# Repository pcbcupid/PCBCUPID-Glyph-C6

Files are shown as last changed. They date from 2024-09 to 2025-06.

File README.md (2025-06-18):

# PCBCUPID-GLYPH-C6-PCB

PCBCUPID-GLYPH-C6

This repo contains open source PCB files for PCBCUPID Glyph C6
This particular PCB is designed using Kicad v8.0

**This design has been built and tested successfully!**
For more details, check out the product pages at

   * [Glyph-C6](https://shop.pcbcupid.com/product/gd002/)

We are here to build India's largest open source hardware community, If you like to support
please consider buying the product from the above link!

[Creative Commons Attribution, Share-Alike license](https://creativecommons.org/licenses/by-sa/4.0/deed.en)
All text above must be included in any redistribution

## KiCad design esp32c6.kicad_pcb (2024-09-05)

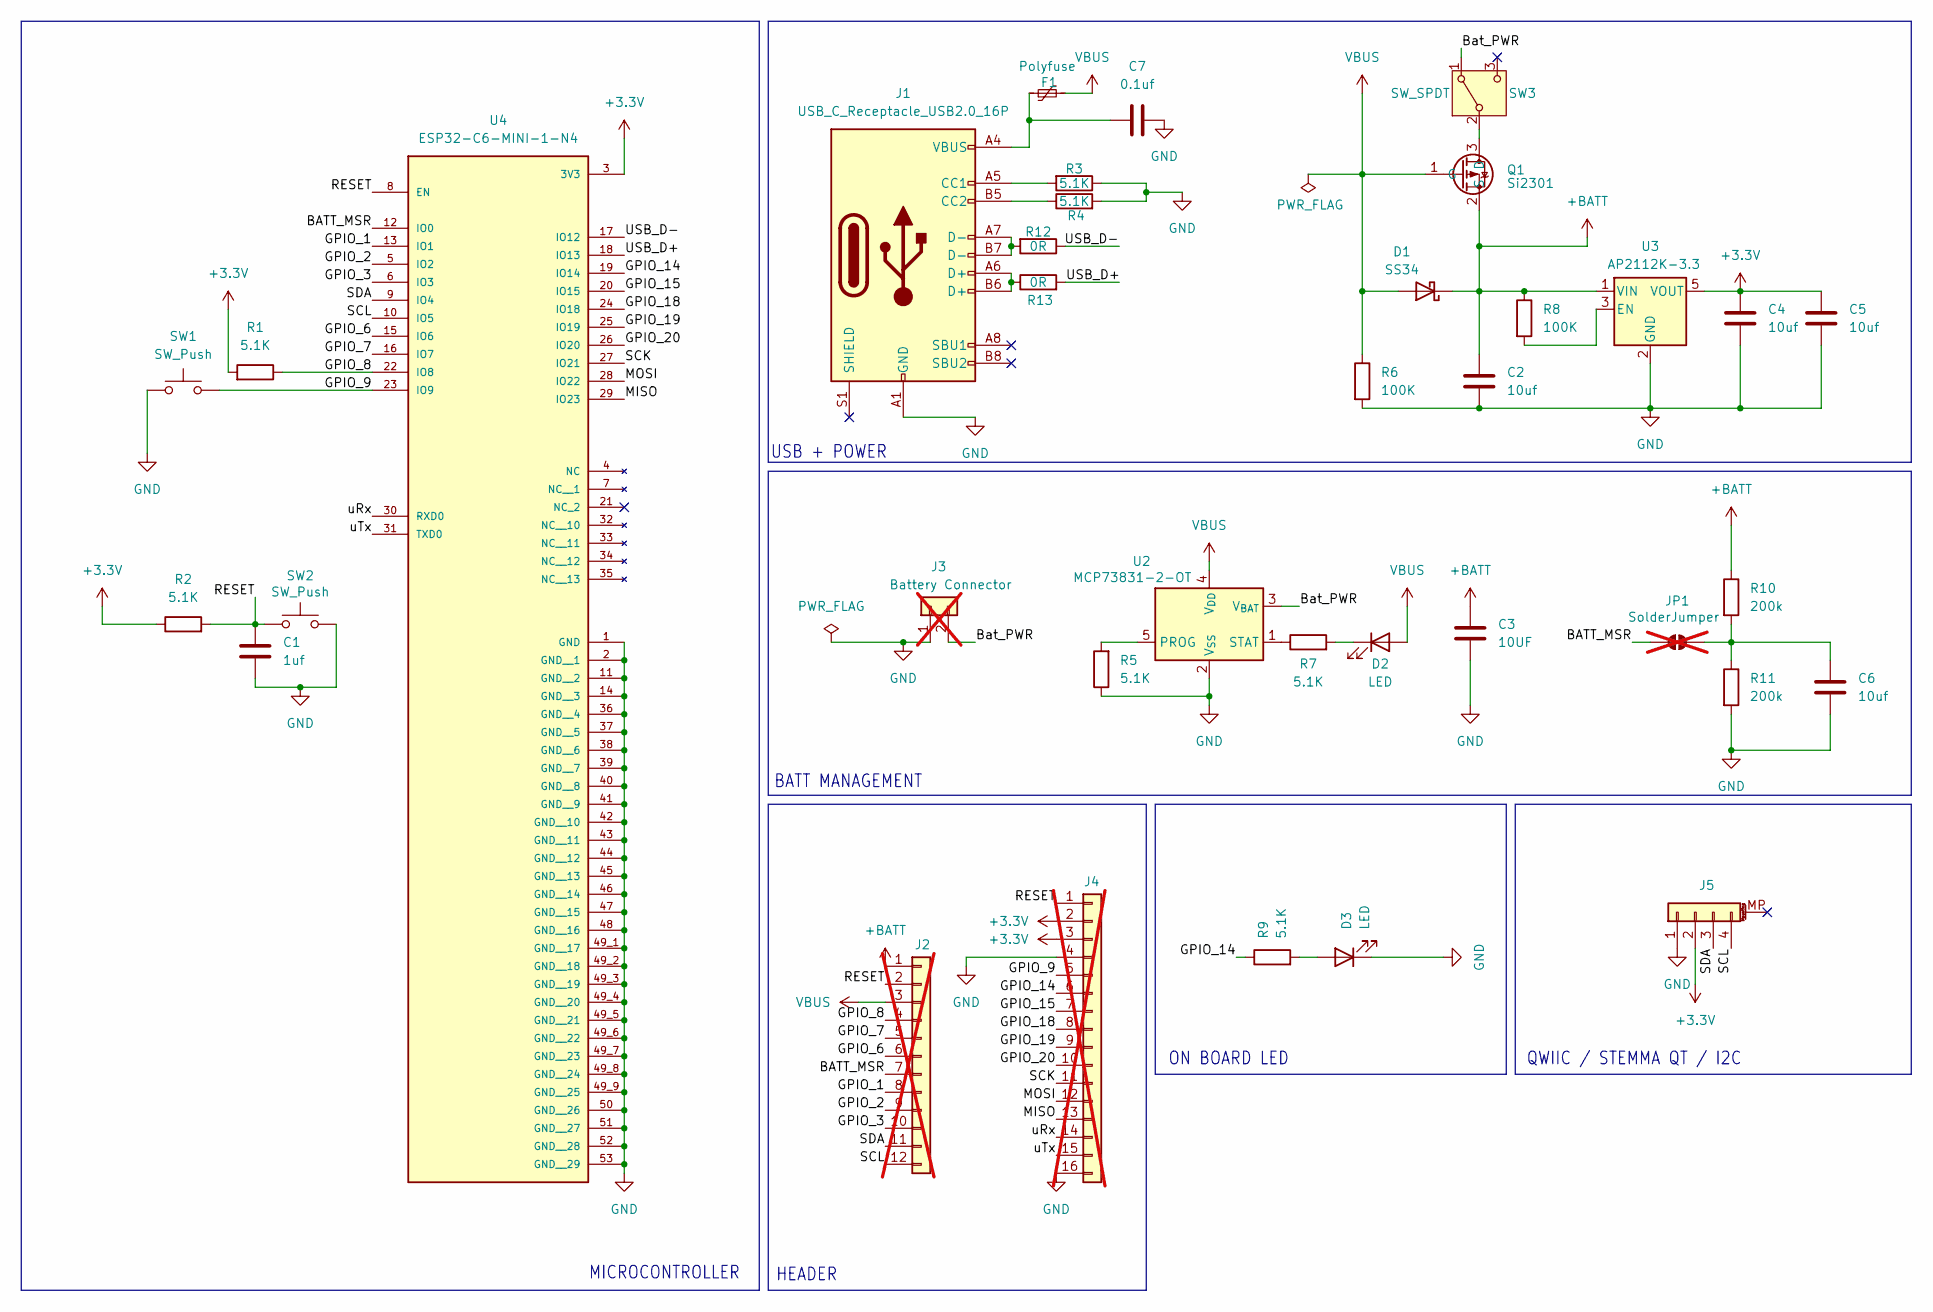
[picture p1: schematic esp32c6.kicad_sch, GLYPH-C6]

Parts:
C1: 1uf; C_0603_1608Metric
C2, C4, C5, C6: 10uf; C_0603_1608Metric
C3: 10UF; C_0603_1608Metric
C7: 0.1uf; C_0603_1608Metric
D1: SS34; D_SMA
D2, D3: LED; LED_0603_1608Metric
F1: Polyfuse; Fuse_0805_2012Metric
J1: USB_C_Receptacle_USB2.0_16P; USB_C_Receptacle_Palconn_UTC16-G
J2: Conn_01x12; PinSocket_1x12_P2.54mm_Vertical; not fitted
J3: Battery Connector; TestPoint_01x02; not fitted
J4: Conn_01x16; PinSocket_1x16_P2.54mm_Vertical; not fitted
J5: Conn_01x04_MountingPin; JST_SH_BM04B-SRSS-TB_1x04-1MP_P1.00mm_Vertical
JP1: SolderJumper; SolderJumper-2_P1.3mm_Open_RoundedPad1.0x1.5mm; not fitted
Q1: Si2301; SOT-23
R1, R2, R3, R4, R5, R7, R9: 5.1K; R_0603_1608Metric
R6, R8: 100K; R_0603_1608Metric
R10, R11: 200k; R_0603_1608Metric
R12, R13: 0R; R_0603_1608Metric
SW1, SW2: SW_Push; SW_SPST_PTS810
SW3: SW_SPDT; SW_SPDT_PCM12
U2: MCP73831-2-OT; SOT-23-5
U3: AP2112K-3.3; SOT-23-5
U4: ESP32-C6-MINI-1-N4; ESP32-C6-MINI-1_EXP; PARTREV v1.0

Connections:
+3.3V: C4.1, C5.1, J4.2, J4.3, J5.2, R1.2, R2.1, U3.5 (VOUT), U4.3 (3V3)
+BATT: C2.1, C3.1, D1.1 (K), J2.1, Q1.2 (S), R8.1, R10.1, U3.1 (VIN)
/BATT_MSR: J2.7, JP1.1 (A), U4.12 (IO0)
/Bat_PWR: J3.2, SW3.1 (A), U2.3 (V_{BAT})
/D+: J1.A6 (D+), J1.B6 (D+), R13.1
/D-: J1.A7 (D-), J1.B7 (D-), R12.2
/GPIO_1: J2.8, U4.13 (IO1)
/GPIO_2: J2.9, U4.5 (IO2)
/GPIO_3: J2.10, U4.6 (IO3)
/GPIO_6: J2.6, U4.15 (IO6)
/GPIO_7: J2.5, U4.16 (IO7)
/GPIO_8: J2.4, R1.1, U4.22 (IO8)
/GPIO_9: J4.5, SW1.1, U4.23 (IO9)
/GPIO_14: J4.6, R9.1, U4.19 (IO14)
/GPIO_15: J4.7, U4.20 (IO15)
/GPIO_18: J4.8, U4.24 (IO18)
/GPIO_19: J4.9, U4.25 (IO19)
/GPIO_20: J4.10, U4.26 (IO20)
/MISO: J4.13, U4.29 (IO23)
/MOSI: J4.12, U4.28 (IO22)
/RESET: C1.1, J2.2, J4.1, R2.2, SW2.1, U4.8 (EN)
/SCK: J4.11, U4.27 (IO21)
/SCL: J2.12, J5.4, U4.10 (IO5)
/SDA: J2.11, J5.3, U4.9 (IO4)
/USB_D+: R13.2, U4.18 (IO13)
/USB_D-: R12.1, U4.17 (IO12)
/uRx: J4.14, U4.30 (RXD0)
/uTx: J4.15, U4.31 (TXD0)
GND: C1.2, C2.2, C3.2, C4.2, C5.2, C6.2, C7.2, D3.1 (K), J1.A1 (GND), J1.A12 (GND), J1.B1 (GND), J1.B12 (GND), J3.1, J4.4, J4.16, J5.1, R3.1, R4.2, R5.1, R6.2, R11.2, SW1.2, SW2.2, U2.2 (V_{SS}), U3.2 (GND), U4.1 (GND), U4.2 (GND__1), U4.11 (GND__2), U4.14 (GND__3), U4.36 (GND__4), U4.37 (GND__5), U4.38 (GND__6), U4.39 (GND__7), U4.40 (GND__8), U4.41 (GND__9), U4.42 (GND__10), U4.43 (GND__11), U4.44 (GND__12), U4.45 (GND__13), U4.46 (GND__14), U4.47 (GND__15), U4.48 (GND__16), U4.49_1 (GND__17), U4.49_2 (GND__18), U4.49_3 (GND__19), U4.49_4 (GND__20), U4.49_5 (GND__21), U4.49_6 (GND__22), U4.49_7 (GND__23), U4.49_8 (GND__24), U4.49_9 (GND__25), U4.50 (GND__26), U4.51 (GND__27), U4.52 (GND__28), U4.53 (GND__29)
unnamed: C7.1, F1.1, J1.A4 (VBUS), J1.A9 (VBUS), J1.B4 (VBUS), J1.B9 (VBUS)
unnamed: D2.1 (K), R7.2
unnamed: D3.2 (A), R9.2
unnamed: J1.A5 (CC1), R3.2
unnamed: J1.B5 (CC2), R4.1
unnamed: C6.1, JP1.2 (B), R10.2, R11.1
unnamed: Q1.3 (D), SW3.2 (B)
unnamed: R5.2, U2.5 (PROG)
unnamed: R7.1, U2.1 (STAT)
unnamed: R8.2, U3.3 (EN)
VBUS: D1.2 (A), D2.2 (A), F1.2, J2.3, Q1.1 (G), R6.1, U2.4 (V_{DD})

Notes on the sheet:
ON BOARD LED
HEADER
BATT MANAGEMENT
QWIIC / STEMMA QT / I2C
MICROCONTROLLER
USB + POWER

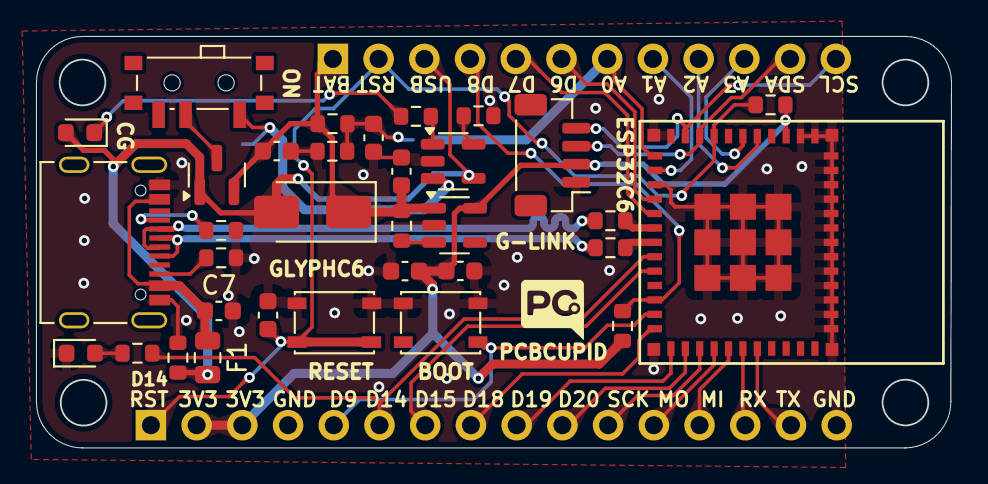
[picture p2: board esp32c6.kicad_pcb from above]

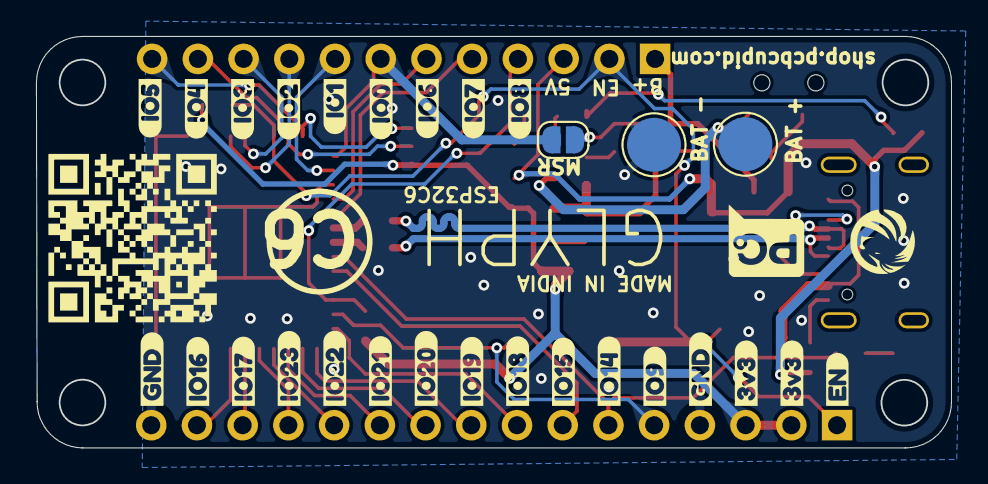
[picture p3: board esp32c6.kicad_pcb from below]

Board: 2 copper layers, 50.8 x 22.9 mm, 62 parts (28 on the bottom side), 40 nets.

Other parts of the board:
kibuzzard-668B7A7C: G***; kibuzzard-668B7A7C
kibuzzard-668B7A62, kibuzzard-668B7A62#2: G***; kibuzzard-668B7A62
kibuzzard-668B789B, kibuzzard-668B789B#2: G***; kibuzzard-668B789B
kibuzzard-668CCB9F: G***; kibuzzard-668CCB9F
kibuzzard-668CCB83: G***; kibuzzard-668CCB83
kibuzzard-668D15B0: G***; kibuzzard-668D15B0
kibuzzard-668D15B6: G***; kibuzzard-668D15B6
kibuzzard-668D15C1: G***; kibuzzard-668D15C1
kibuzzard-668D15F0: G***; kibuzzard-668D15F0
kibuzzard-668D15F7: G***; kibuzzard-668D15F7
kibuzzard-668D16B5: G***; kibuzzard-668D16B5
kibuzzard-668D17D0: G***; kibuzzard-668D17D0
kibuzzard-668D17D6: G***; kibuzzard-668D17D6
kibuzzard-668D170D: G***; kibuzzard-668D170D
kibuzzard-668D171B: G***; kibuzzard-668D171B
kibuzzard-668D175C: G***; kibuzzard-668D175C
kibuzzard-668D176A: G***; kibuzzard-668D176A
kibuzzard-668D1619: G***; kibuzzard-668D1619
kibuzzard-668D1621: G***; kibuzzard-668D1621
kibuzzard-668D1715: G***; kibuzzard-668D1715
kibuzzard-668D1721: G***; kibuzzard-668D1721
kibuzzard-668D1727: G***; kibuzzard-668D1727
kibuzzard-668D1756: G***; kibuzzard-668D1756

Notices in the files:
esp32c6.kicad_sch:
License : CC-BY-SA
